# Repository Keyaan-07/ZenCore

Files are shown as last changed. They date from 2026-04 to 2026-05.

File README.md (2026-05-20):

# Zencore F4
Zencore F4 is a low-cost, Pico sized STM32F411 Development board along with an SD card reader for SDMMC development. The footprint is breadboard compatible and it features the W25Q128JVS 128Mbit Flash chip for non-volatile storage. Unlike traditional devboards, this features a compact form factor. The pins are labelled on the bottom side of the PCB.  
I want to use the stm32f411 mcu for a bigger project and thus i will be experimenting with this one(hence the SD card interface). Just plug in the USB-C to your PC and upload the code via STM32cubeIDE to get started.  
To build this, clone/download this repository, and in the /hardware/production folder, use the files and the bom to order the parts yourself and assemble it by hand!

See the board on [KiCanvas](https://kicanvas.org/?github=https://github.com/Keyaan-07/ZenCore/tree/main/hardware)
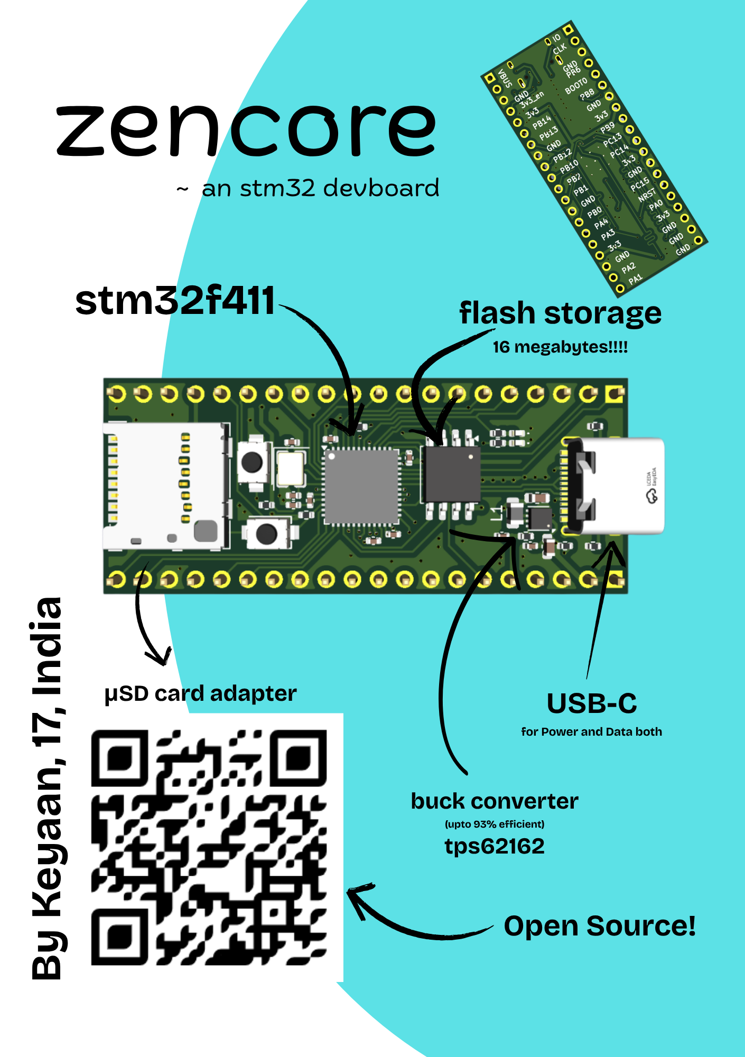
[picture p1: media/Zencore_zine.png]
magazine page

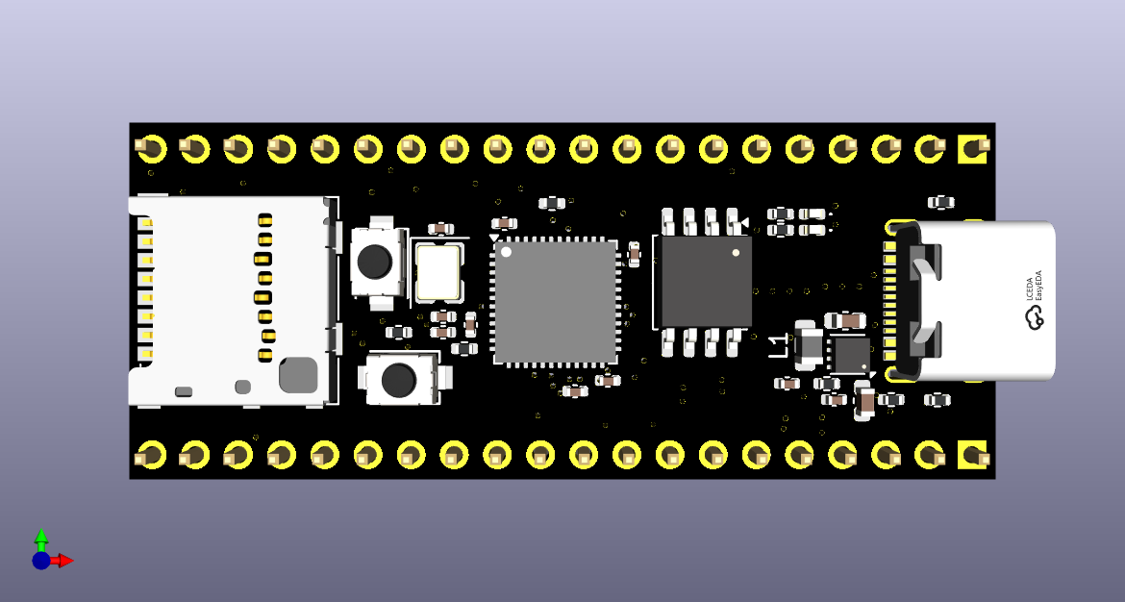
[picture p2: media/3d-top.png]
3d-top

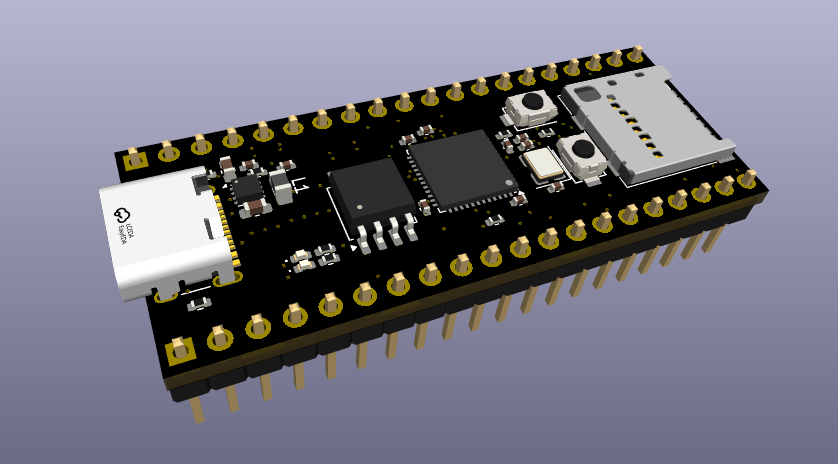
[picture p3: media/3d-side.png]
3d-side

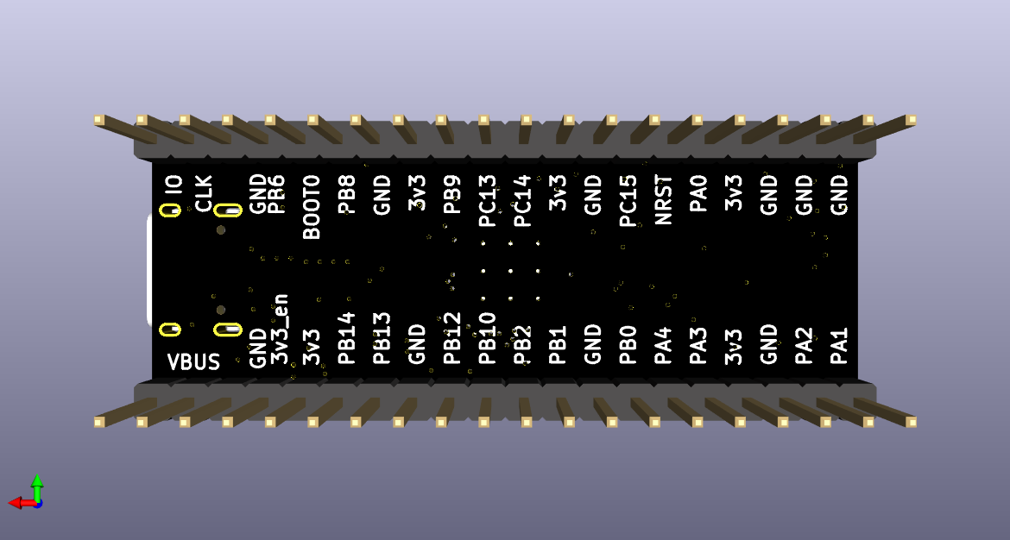
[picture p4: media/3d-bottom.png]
3d-bottom

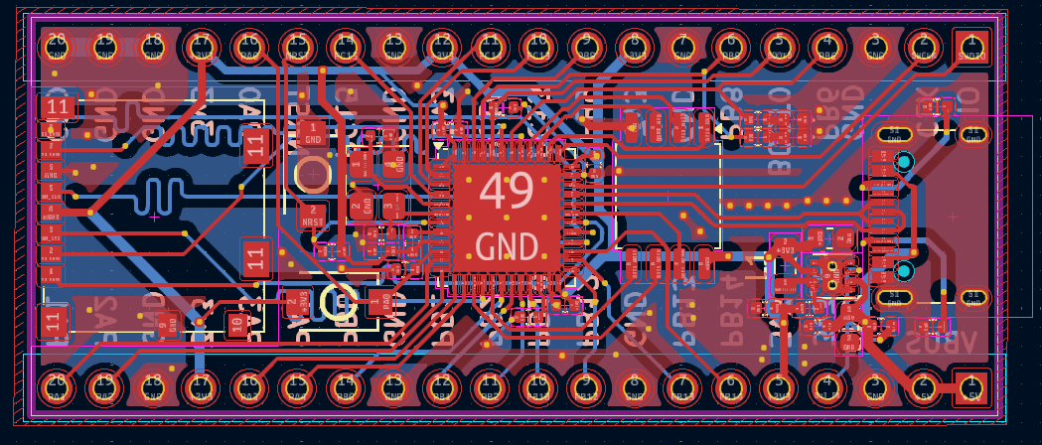
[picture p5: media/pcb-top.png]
pcb-top

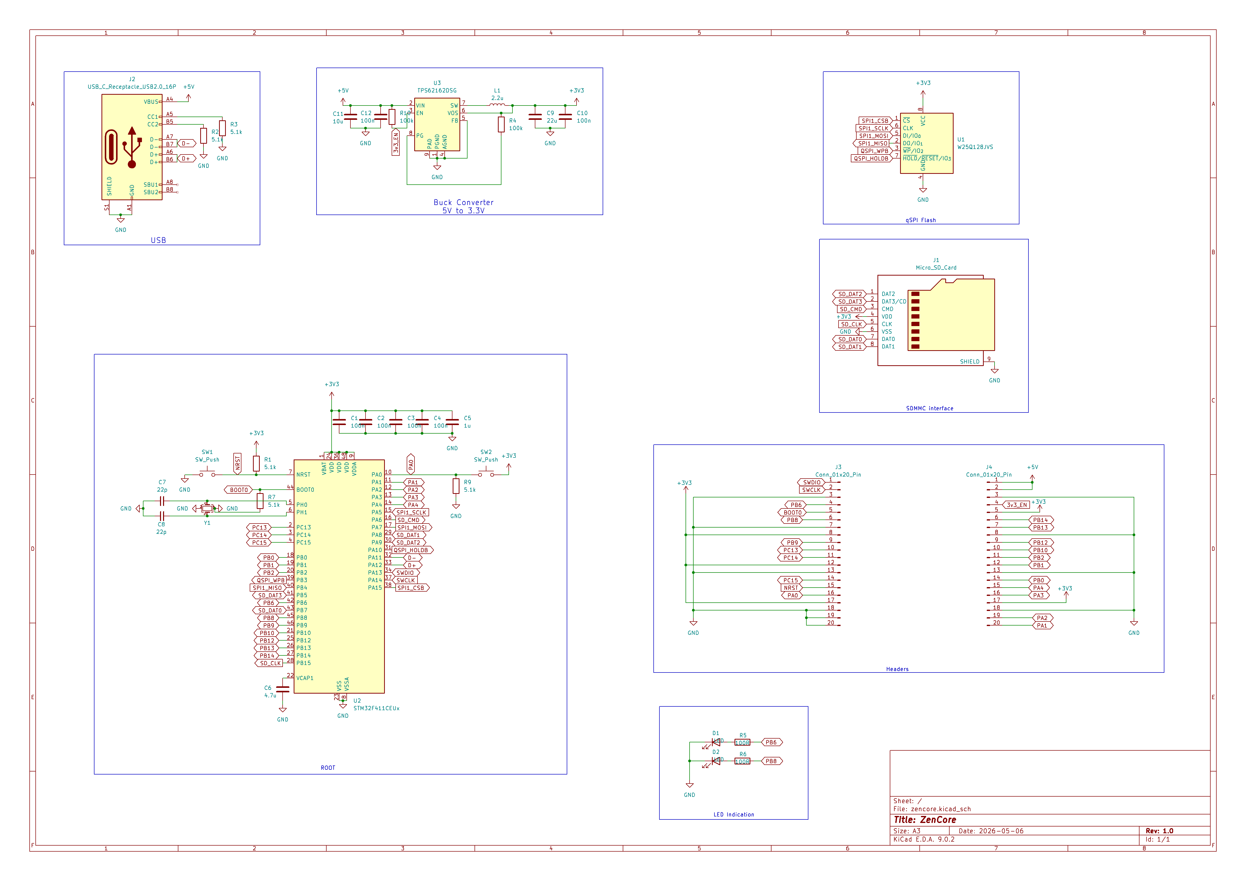
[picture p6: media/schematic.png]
schematic


# BOM
|Designator |Function |Value |Footprint |Quantity|Price |Amount|Order|Link |
|---|---|---|---|---|---|---|-----|---|
|PCB |PCB |21x51 |2 layer board |5 |0.42 |2.1 |Yes  |https://jlcpcb.com |
|PCB Stencil |Stencil |40x55 |stencil |1 |3.05 |3.05  |Yes  |https://jlcpcb.com |
|C1, C10, C12, C2, C3, C4|Capacitor |100n |402 |12 |0.0075 |0.09  |No |https://www.lcsc.com/product-detail/C426067.html  |
|C11 |Capacitor |10u |603 |2 |0.02 |0.04  |No |https://www.lcsc.com/product-detail/C7393892.html |
|C5 |Capacitor |1u |402 |20 |0.03 |0.6 |yes  |https://www.lcsc.com/product-detail/C1518208.html |
|C6 |Capacitor |4.7u |402 |10 |0.04 |0.4 |Yes  |https://www.lcsc.com/product-detail/C426094.html  |
|C7, C8 |Capacitor |22p |402 |4 |0.03 |0.12  |No |https://www.lcsc.com/product-detail/C882567.html  |
|C9 |Capacitor |22u |603 |10 |0.014 |0.14  |Yes  |https://www.lcsc.com/product-detail/C86295.html |
|D1, D2 |LED |LED |402 |50 |0.01 |0.5 |Yes  |https://www.lcsc.com/product-detail/C7496805.html |
|J1 |SD card connector|Micro_SD_Card |microSD_HC_Molex_104031-0811 |2 |0.63 |1.26  |Yes  |https://www.lcsc.com/product-detail/C585350.html  |
|J2 |USB-C Receptacle |USB_C_Receptacle_USB2.0_16P|USB_C_Receptacle_XKB_U262-16XN-4BVC11 |10 |0.066 |0.66  |Yes  |https://www.lcsc.com/product-detail/C393939.html  |
|J3, J4 |header |Conn_01x20_Pin |PinHeader_1x20_P2.54mm_Vertical |2 |DNP |DNP |DNP  |DNP |
|L1 |Inductor |2.2u |805 |5 |0.1 |0.5 |Yes  |https://www.lcsc.com/product-detail/C48945029.html|
|R1, R2, R3, R7, R9 |Resistors |5.1k |402 |10 |0.005 |0.05  |No |https://www.lcsc.com/product-detail/C278598.html  |
|R10, R4 |Resistors |100k |402 |4 |0.02 |0.08  |No |https://www.lcsc.com/product-detail/C313329.html  |
|R5, R6 |Resistors |100R |402 |4 |0.037 |0.148 |No |https://www.lcsc.com/product-detail/C427204.html  |
|SW1, SW2 |Switch |SW_Push |SW-SMD_L3.9-W3.0-P4.45 |10 |0.056 |0.56  |Yes  |https://www.lcsc.com/product-detail/C720477.html  |
|U1 |flash chip |W25Q128JVS |SOIC-8_5.3x5.3mm_P1.27mm |2 |DNP |DNP |DNP  |DNP |
|U2 |MCU |STM32F411CEUx |QFN-48-1EP_7x7mm_P0.5mm_EP5.6x5.6mm |2 |3.87 |7.74  |Yes  |https://www.lcsc.com/product-detail/C60420.html |
|U3 |Buck Convertor |TPS62162DSG |WSON-8-1EP_2x2mm_P0.5mm_EP0.9x1.6mm_ThermalVias|2 |0.86 |1.72  |Yes  |https://www.lcsc.com/product-detail/C40256.html |
|Y1 |Crystal |25MHz |Crystal_SMD_3225-4Pin_3.2x2.5mm |2 | |0 |No |https://www.lcsc.com/product-detail/C521601.html  |
| | | | | |Shipping |3.9 | | |
| | | | | |Shipping(PCB)|11.13 | | |
| | | | | |Total |34.788| | |

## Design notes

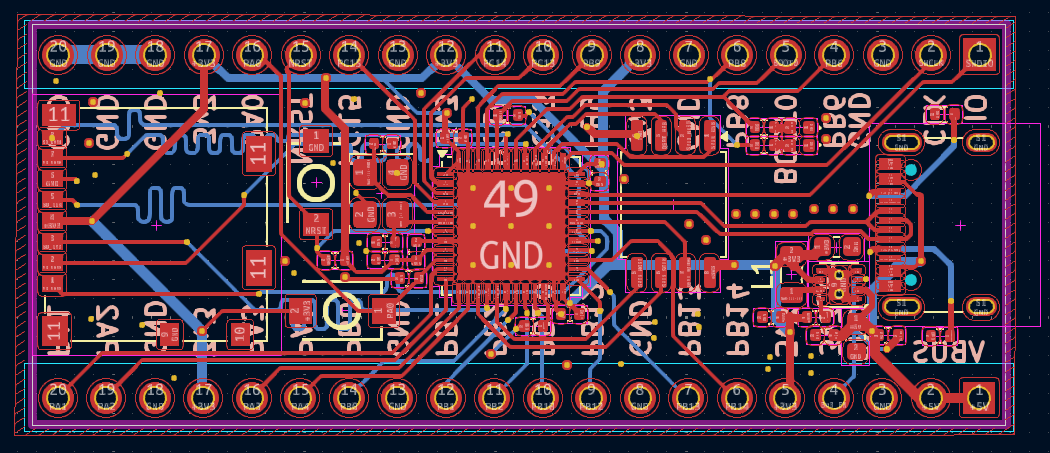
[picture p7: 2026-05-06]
media/pcb-top-no-zone.png

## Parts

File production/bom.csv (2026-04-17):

Designator | Footprint | Quantity | Value | LCSC Part #
C1, C10, C12, C2, C3, C4 | 0402 | 6 | 100n
C11 | 0603 | 1 | 10u
C5 | 0402 | 1 | 1u
C6 | 0402 | 1 | 4.7u
C7, C8 | 0402 | 2 | C_Small
C9 | 0603 | 1 | 22u
D1, D2 | 0402 | 2 | LED
J1 | microSD_HC_Molex_104031-0811 | 1 | Micro_SD_Card
J2 | USB_C_Receptacle_XKB_U262-16XN-4BVC11 | 1 | USB_C_Receptacle_USB2.0_16P
J3, J4 | PinHeader_1x20_P2.54mm_Vertical | 2 | Conn_01x20_Pin
L1 | 0603 | 1 | 2.2u
R1, R2, R3, R7, R9 | 0402 | 5 | 5.1k
R10, R4 | 0402 | 2 | 100k
R5, R6 | 0402 | 2 | 100R
SW1, SW2 | SW-SMD_L3.9-W3.0-P4.45 | 2 | SW_Push
U1 | SOIC-8_5.3x5.3mm_P1.27mm | 1 | W25Q128JVS
U2 | QFN-48-1EP_7x7mm_P0.5mm_EP5.6x5.6mm | 1 | STM32F411CEUx
U3 | WSON-8-1EP_2x2mm_P0.5mm_EP0.9x1.6mm_ThermalVias | 1 | TPS62162DSG
Y1 | Crystal_SMD_3225-4Pin_3.2x2.5mm | 1 | Crystal_GND24_Small

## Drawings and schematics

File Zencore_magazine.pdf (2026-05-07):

# zencore

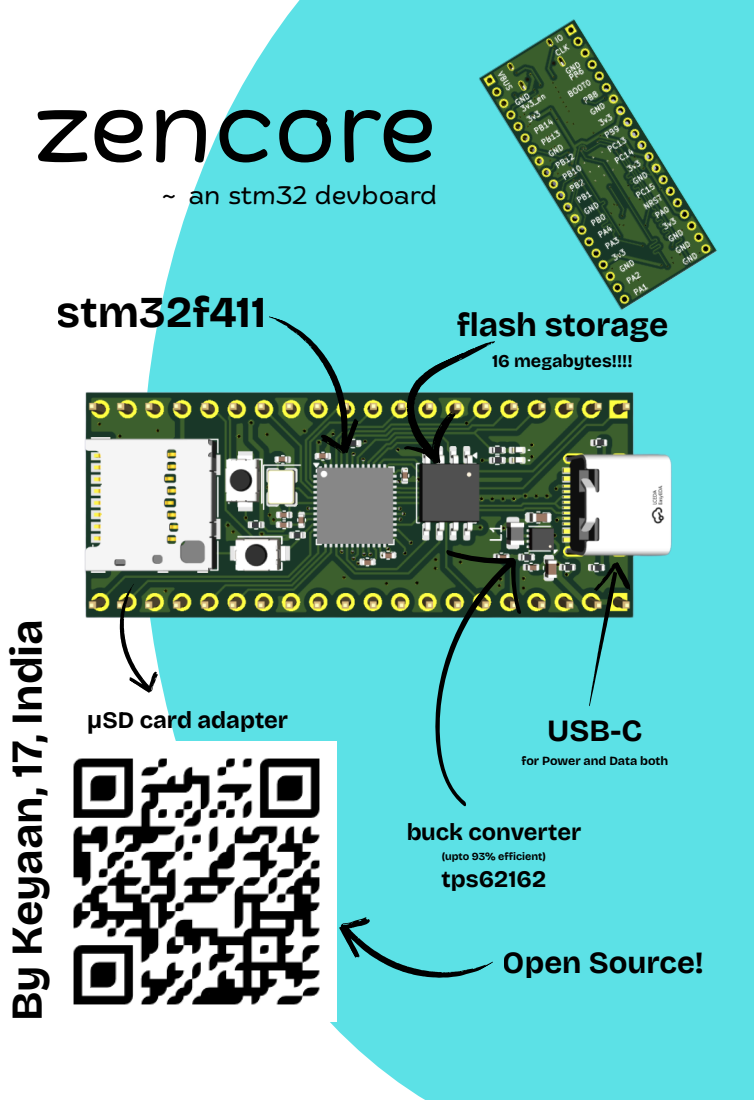
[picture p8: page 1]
stm32f411; Open Source!; USB-C; ~ an stm32 devboard; flash storage; 16 megabytes!!!!; buck converter; (upto 93% efficient) tps62162

μSD card adapter

for Power and Data both

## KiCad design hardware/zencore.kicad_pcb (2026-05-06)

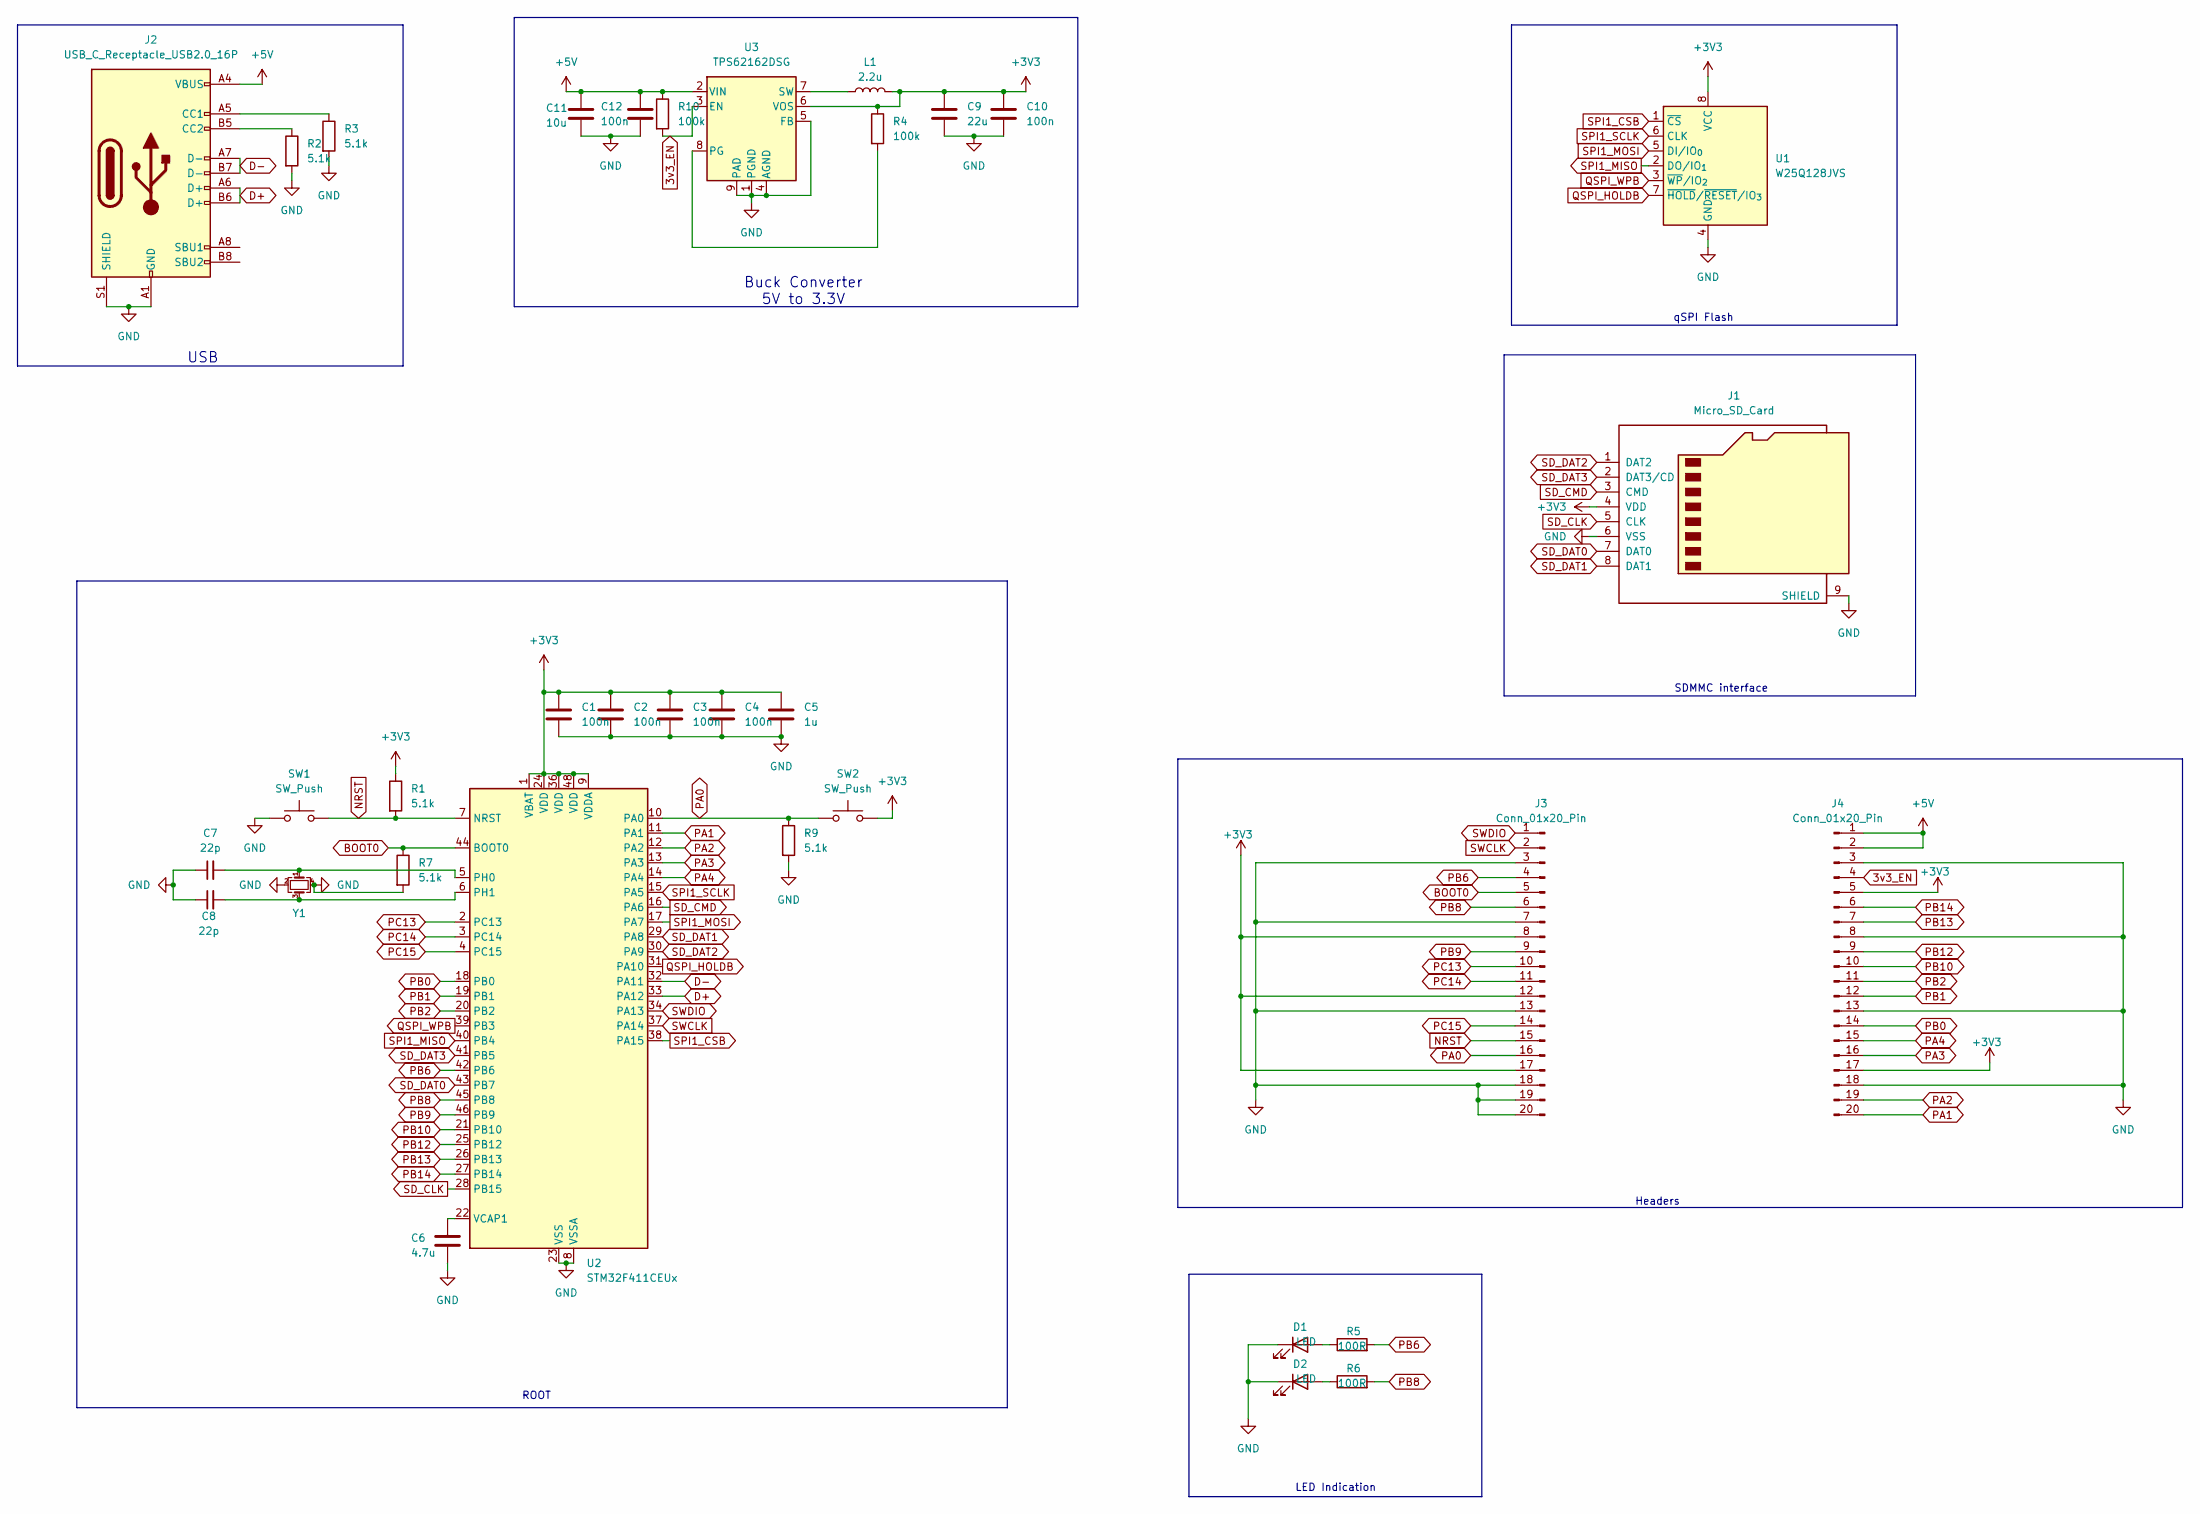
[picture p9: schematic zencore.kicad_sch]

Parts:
C1, C2, C3, C4, C10, C12: 100n; C_0402_1005Metric
C5: 1u; C_0402_1005Metric
C6: 4.7u; C_0402_1005Metric
C7, C8: 22p; C_0402_1005Metric
C9: 22u; C_0603_1608Metric
C11: 10u; C_0603_1608Metric
D1, D2: LED; LED_0402_1005Metric
J1: Micro_SD_Card; microSD_HC_Molex_104031-0811
J2: USB_C_Receptacle_USB2.0_16P; USB_C_Receptacle_XKB_U262-16XN-4BVC11
J3, J4: Conn_01x20_Pin; PinHeader_1x20_P2.54mm_Vertical
L1: 2.2u; L_0805_2012Metric
R1, R2, R3, R7, R9: 5.1k; R_0402_1005Metric
R4, R10: 100k; R_0402_1005Metric
R5, R6: 100R; R_0402_1005Metric
SW1, SW2: SW_Push; SW-SMD_L3.9-W3.0-P4.45
U1: W25Q128JVS; SOIC-8_5.3x5.3mm_P1.27mm
U2: STM32F411CEUx; QFN-48-1EP_7x7mm_P0.5mm_EP5.6x5.6mm
U3: TPS62162DSG; WSON-8-1EP_2x2mm_P0.5mm_EP0.9x1.6mm_ThermalVias
Y1: Crystal_GND24_Small; Crystal_SMD_3225-4Pin_3.2x2.5mm

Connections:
3v3_EN: J4.4, R10.2, U3.3 (EN)
+3V3: C1.1, C2.1, C3.1, C4.1, C5.1, C9.1, C10.1, J1.4 (VDD), J3.8, J3.12, J3.17, J4.5, J4.17, L1.2, R1.1, R4.1, SW2.2, U1.8 (VCC), U2.1 (VBAT), U2.9 (VDDA), U2.24 (VDD), U2.36 (VDD), U2.48 (VDD), U3.6 (VOS)
+5V: C11.1, C12.1, J2.A4 (VBUS), J2.A9 (VBUS), J2.B4 (VBUS), J2.B9 (VBUS), J4.1, J4.2, R10.1, U3.2 (VIN)
BOOT0: J3.5, R7.1, U2.44 (BOOT0)
D+: J2.A6 (D+), J2.B6 (D+), U2.33 (PA12)
D-: J2.A7 (D-), J2.B7 (D-), U2.32 (PA11)
GND: C1.2, C2.2, C3.2, C4.2, C5.2, C6.2, C7.1, C8.1, C9.2, C10.2, C11.2, C12.2, D1.1 (K), D2.1 (K), J1.6 (VSS), J1.9 (SHIELD), J2.A1 (GND), J2.A12 (GND), J2.B1 (GND), J2.B12 (GND), J2.S1 (SHIELD), J3.3, J3.7, J3.13, J3.18, J3.19, J3.20, J4.3, J4.8, J4.13, J4.18, R2.2, R3.2, R7.2, R9.2, SW1.1, U1.4 (GND), U2.8 (VSSA), U2.23 (VSS), U2.35 (VSS), U2.47 (VSS), U2.49 (VSS), U3.1 (PGND), U3.4 (AGND), U3.5 (FB), U3.9 (PAD), Y1.2, Y1.4
NRST: J3.15, R1.2, SW1.2, U2.7 (NRST)
unnamed: D1.2 (A), R5.1
unnamed: D2.2 (A), R6.1
unnamed: J2.A5 (CC1), R3.1
unnamed: J2.B5 (CC2), R2.1
unnamed: C7.2, U2.5 (PH0), Y1.1
unnamed: C8.2, U2.6 (PH1), Y1.3
unnamed: C6.1, U2.22 (VCAP1)
unnamed: R4.2, U3.8 (PG)
unnamed: L1.1, U3.7 (SW)
PA0: J3.16, R9.1, SW2.1, U2.10 (PA0)
PA1: J4.20, U2.11 (PA1)
PA2: J4.19, U2.12 (PA2)
PA3: J4.16, U2.13 (PA3)
PA4: J4.15, U2.14 (PA4)
PB0: J4.14, U2.18 (PB0)
PB1: J4.12, U2.19 (PB1)
PB2: J4.11, U2.20 (PB2)
PB6: J3.4, R5.2, U2.42 (PB6)
PB8: J3.6, R6.2, U2.45 (PB8)
PB9: J3.9, U2.46 (PB9)
PB10: J4.10, U2.21 (PB10)
PB12: J4.9, U2.25 (PB12)
PB13: J4.7, U2.26 (PB13)
PB14: J4.6, U2.27 (PB14)
PC13: J3.10, U2.2 (PC13)
PC14: J3.11, U2.3 (PC14)
PC15: J3.14, U2.4 (PC15)
QSPI_HOLDB: U1.7 (~HOLD/~RESET/IO_{3}), U2.31 (PA10)
QSPI_WPB: U1.3 (~WP/IO_{2}), U2.39 (PB3)
SD_CLK: J1.5 (CLK), U2.28 (PB15)
SD_CMD: J1.3 (CMD), U2.16 (PA6)
SD_DAT0: J1.7 (DAT0), U2.43 (PB7)
SD_DAT1: J1.8 (DAT1), U2.29 (PA8)
SD_DAT2: J1.1 (DAT2), U2.30 (PA9)
SD_DAT3: J1.2 (DAT3/CD), U2.41 (PB5)
SPI1_CSB: U1.1 (~CS), U2.38 (PA15)
SPI1_MISO: U1.2 (DO/IO_{1}), U2.40 (PB4)
SPI1_MOSI: U1.5 (DI/IO_{0}), U2.17 (PA7)
SPI1_SCLK: U1.6 (CLK), U2.15 (PA5)
SWCLK: J3.2, U2.37 (PA14)
SWDIO: J3.1, U2.34 (PA13)

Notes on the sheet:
LED Indication
SDMMC interface
ROOT
Headers
qSPI Flash
USB
Buck Converter 5V to 3.3V

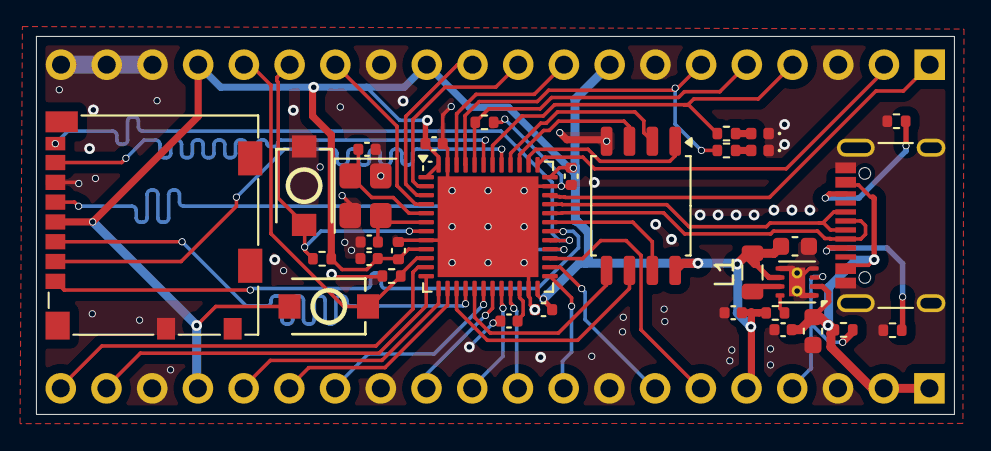
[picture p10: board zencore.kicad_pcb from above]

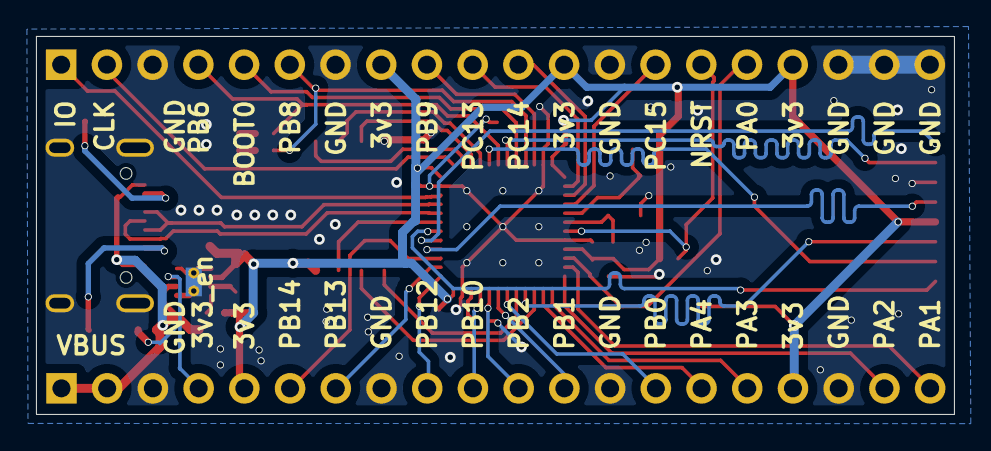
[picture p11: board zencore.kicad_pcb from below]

Board: 2 copper layers, 51.0 x 21.0 mm, 34 parts (2 on the bottom side), 49 nets.

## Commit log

2026-03-12 Hello, World
    [zencore.kicad_pcb, zencore.kicad_sch]
2026-03-18 Worked on the schematic
    [zencore.kicad_pcb, zencore.kicad_sch]
2026-04-17 Routing done
    [bom.csv, designators.csv, positions.csv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]
2026-05-04 3D models added
    [zencore.kicad_pcb]
2026-05-06 PCB production files added
    [bom.csv, designators.csv, positions.csv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]
2026-05-06 Added PCB and 3D model images
2026-05-06 Upload BOM
    [bom.csv]
2026-05-06 Update BOM
2026-05-07 print quality magazine page
